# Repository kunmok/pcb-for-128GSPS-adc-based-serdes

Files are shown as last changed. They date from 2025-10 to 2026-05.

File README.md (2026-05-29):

# PCB for ADC-Based 128 GBaud/s SerDes Receiver
This repository contains the PCB design files for the ADC-based 128 Gbaud/s SerDes Rx project.
The project, named "PDMLSE", refers to a DSP-assisted non-linear equalizer implemented in the Intel16 chip (Q4 2024 Shuttle). 

For more details about the designs and layout, please refer to the [TestPlan.pdf](https://github.com/kunmok/pcb-for-128GSPS-adc-based-serdes/blob/main/docs/TestPlan.pdf), [Fabrication Drawing](https://github.com/kunmok/pcb-for-128GSPS-adc-based-serdes/blob/main/docs/fabrication%20drawing%20with%20blindvia.PDF), [pdmlse_pcb.pdf](https://github.com/kunmok/pcb-for-128GSPS-adc-based-serdes/blob/main/docs/pdmlse_pcb.pdf), or contact Kunmo (kunmok@berkeley.edu). 

# 3D View and PCB Configuration 
## PCB Configuration
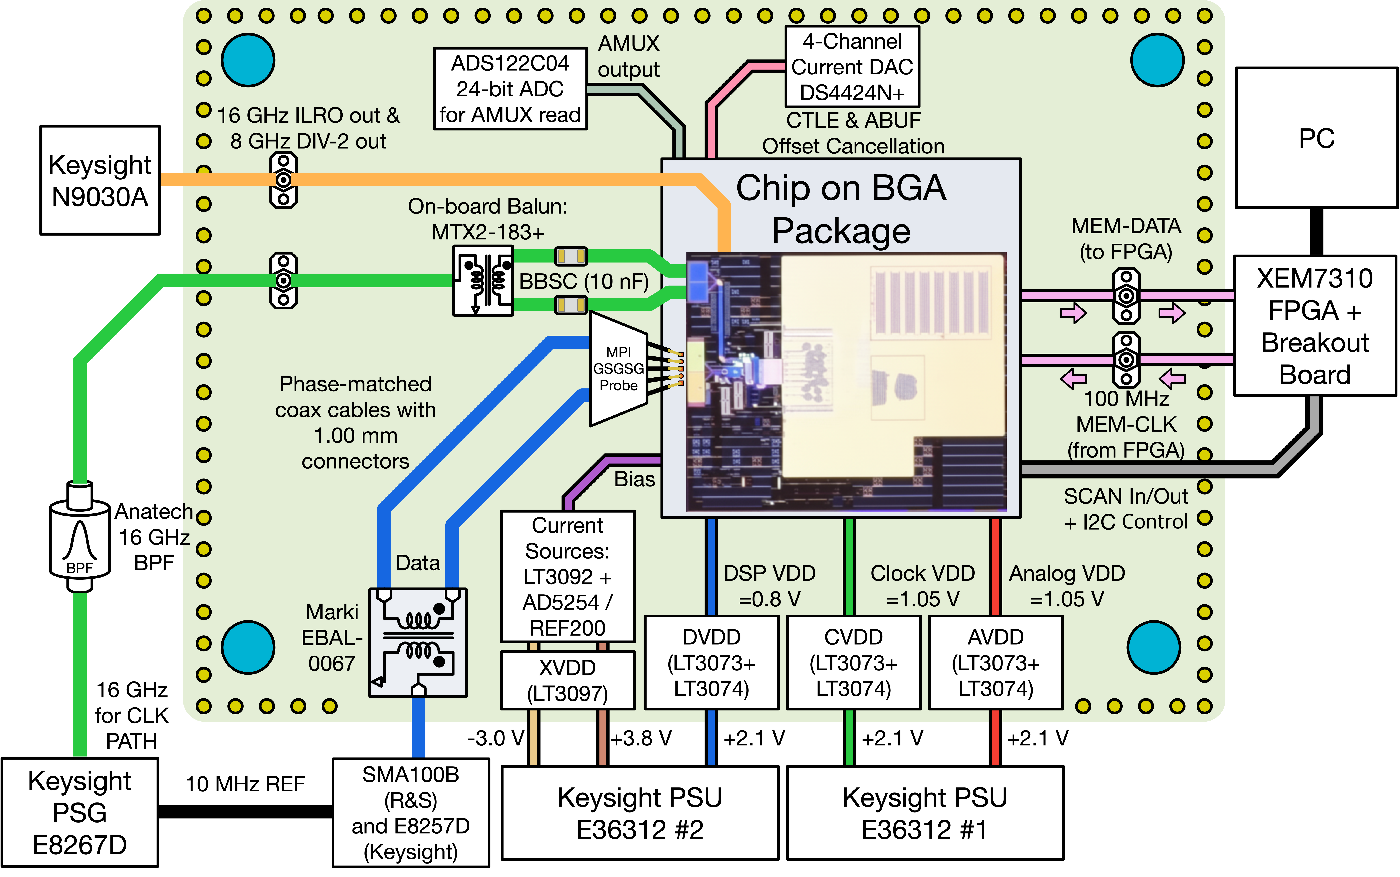
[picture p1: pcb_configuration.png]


### Clock Path (16 GHz) 
- The main 16 GHz clock signal is generated by Keysight’s PSG E8267D and subsequently filtered using an bandpass filter from Anatech (AE16000WB11563), featuring a center frequency of 16 GHz, a bandwidth of +/-50 MHz, and an insertion loss of -4.5 dB. To minimize any frequency offset between the clock and data sources, a 10 MHz reference signal is shared between the signal generators, providing sufficient phase coherence. At a 128 GS/s sampling rate, the 8192-sample (49,152-bit) acquisition window corresponds to only 384 ns, confirming stable synchronization with 10 MHz reference and no need for a 1 GHz reference in/out.

- A stripline configuration is employed for the clock transmission line instead of a grounded coplanar waveguide (GCPW) to further reduce potential coupling between the clock and data paths. The stripline structure also offers greater design flexibility for PCB-to-BGA transitions, enabling a more coaxial-like interface and improved signal integrity.

- For differential signal generation, an on-board balun (MTX2-183+) is used in place of an external balun and additional phase-matched cables. This approach significantly reduces both cost and board area. Although Marki's SMT baluns are viable alternatives, they were out of stock with 3 month of lead-time during the component selection stage. The balanced output of the balun is AC-coupled through Murata BBSC-series DC blockers before being routed to the BGA package.

### Data Path (simulated and measured from 1 GHz to 100 GHz). This path is on the package - not part of the PCB design. 
- Unlike the clock path, the data path is not routed through the PCB. This decision was made because the foundry-provided package has a thickness of 1.2 mm, which introduces significant parasitic inductance through the plated through-holes. This inductance creates a pronounced notch near 60 GHz in the insertion loss profile. The resulting loss could not be adequately compensated by the on-chip CTLE, and therefore, the data signal is directly delivered to the chip using a probe-based approach. The probe landing pads, along with the transmission path between the probe pad, C4 bumps, and on-chip matching network, were modeled and verified using full 3D EM simulations.

- To measure the return loss of the passive front-end matching network, we utilized a Keysight N5290A PNA equipped with an N5293AX03 extension module, alongside an MPI GSGSG probe and calibration substrate. The probe features 1.0mm connectors with a 150 um tip pitch. While a tighter pitch generally yields superior high-frequency performance, the probe landing pad dimensions and pitch were constrained by the package manufacturer's design rules; 150 um was the minimum pitch compliant with DRC requirements.

### Ground Plane and Signal Isolation Strategy
- This PCB uses a single, continuous ground plane shared across seven power domains (AVDD, CVDD, DVDD, XAVDD (±2.5 V), and XDVDD (2.5 V / 3.3 V)). A unified ground provides a more predictable return path, particularly because full-board HFSS simulation is impractical given the board’s size and complexity. To reduce unwanted coupling between domains, the 16-GHz clock routing is confined to the left side of the board, while digital control and interface signals (I²C bus, scan-chain bus, memory read channel, and associated clocks) are routed on the right. The regulated power supplies are crammed in the south side, and analog bias current generation components and routings are placed in the bottom side of the board. The same unified-ground strategy is also used in the IC. On-chip, the analog, clock, and digital supply domains are more tightly partitioned through floorplanning, dedicated decoupling, and guard structures to mitigate coupling.
- During testing, all bench power supplies are operated with their local return (floating with respect to earth), and their earth GND (green port) is not connected to the PCB. This is intentional: the RF return of the 16-GHz clock source (Keysight E8267D PSG) is inherently referenced to earth ground, and the clock source remains continuously connected to the board. As a result, the PCB is earth-referenced through a single point (the RF source connection), effectively implementing a star-ground configuration and avoiding unintended ground loops through multiple instruments. The GSGSG probe is also earth-referenced; however, it primarily provides a return path for the package ground rather than the PCB ground. While the PCB and package ultimately share a common ground, they are separated by finite impedance, so these ground references are not strictly identical at high frequency.

### Power Supply Network
- A cascaded LDO topology—comprising LT3073 followed by LT3074—was implemented to enhance the overall PSRR.
- Murata's NFM-series capacitors are mainly used as decaps. Decaps on L1 (front side) are mainly 10 uF NFM capacitors, and decaps on L6 (back side) are 1 uF NFM capacitors.
- Unlike the common practice of selecting three different capacitor values to cover a broad frequency range, this design uses only two values. The Murata NFM decaps exhibit a very high self-resonant frequency, so their self-resonant behavior does not require careful staggering across multiple values. The smaller 1 uF value on L6 is chosen to account for the via inductance between L1 and L6.
- On the chip side, a substantial amount of MIM decaps plus MOM caps are connected in series with a 0.5 Ω resistance. This intentional ESR overdamps the on-chip PDN, improving resiliency against Ldi/dt noise. This behavior was verified via Spectre simulation.

### Bias Generation
- Backside of the PCB mostly contain bias generation circuit. For bias current generation, a combination of LT3092 and AD5252/AD5254 series digitally programmable resistors was used, enabling flexible bias-level optimization through I2C control.
- REF200s are used for non-programmable bias (cascode bias, CMFB OTA bias, and misc 100 uA). 

### AMUX for Analog Signal Monitoring and CTLE+ABUF Offset Cancellation 
- The chip integrates an on-chip analog multiplexer (AMUX) to monitor various DC bias points, including the CTLE and ABUF bias and output DC voltages as well as local VDD nodes across the die. The AMUX output is routed to an on-board unity-gain buffer, which then drives a 24-bit ADC (ADS122C04) for precision measurement. In addition, a DS4424N+ four-channel current DAC is used for CTLE and ABUF offset cancellation.

## PCB Front-Side: 16 GHz CLK Path, LDOs, ADC, and Connectors
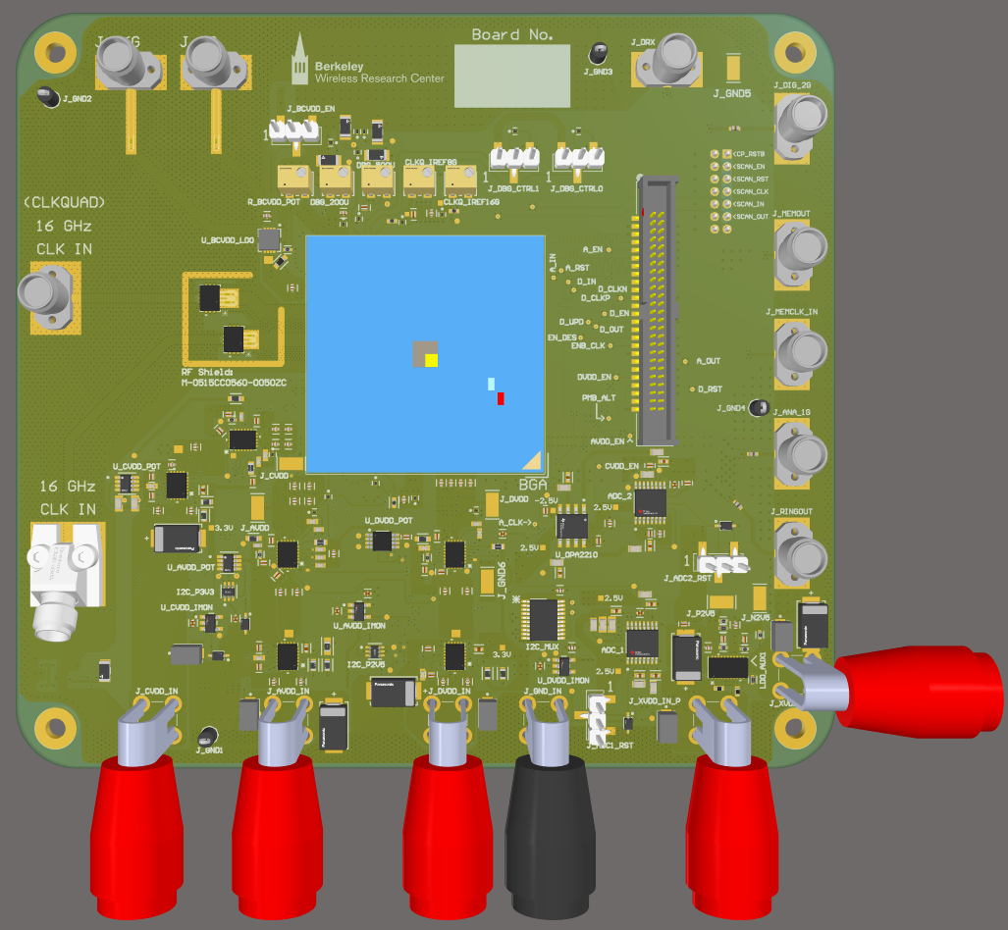
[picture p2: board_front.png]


## PCB Back-Side: Bias Generation (Fixed and Programmable) and Offset Cal IDAC
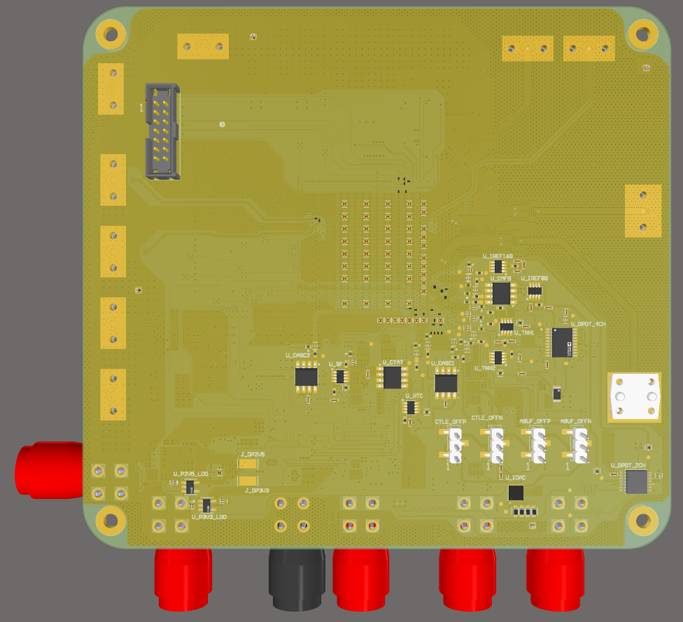
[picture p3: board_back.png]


## Photos 
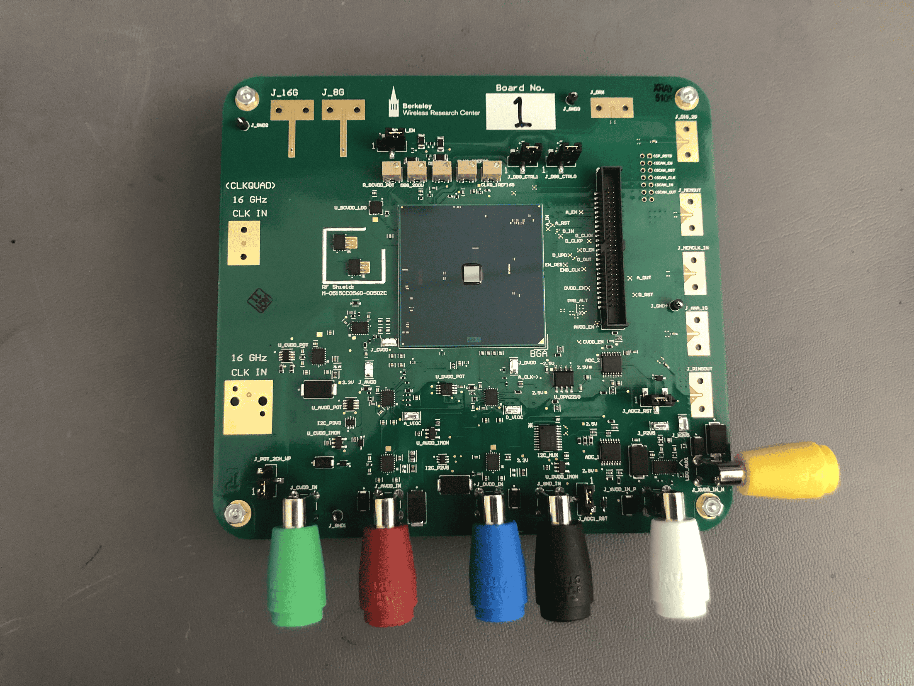
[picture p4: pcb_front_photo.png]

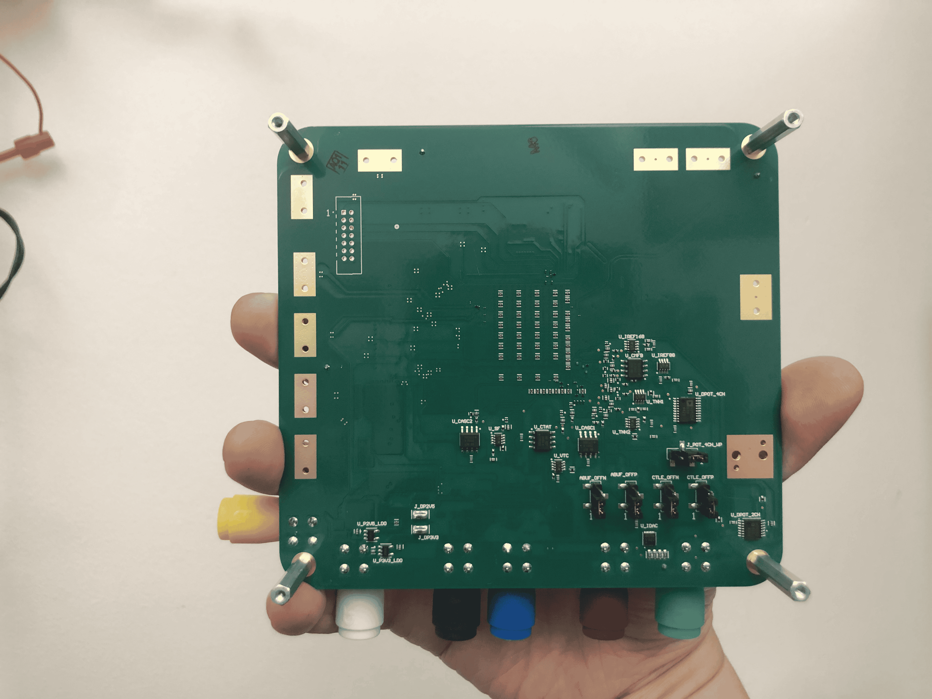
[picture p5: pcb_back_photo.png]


## Author

Designed by **Kunmo Kim** — [kunmo.kim0225@gmail.com](mailto:kunmo.kim0225@gmail.com) ·
[kunmok.github.io](https://kunmok.github.io)

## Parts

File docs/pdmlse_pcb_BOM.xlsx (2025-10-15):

Line # | Name | Description | Designator | Quantity | Alternative Group Name | Manufacturer 1 | Manufacturer Part Number 1 | Supplier 1 | Supplier Part Number 1 | Supplier Unit Price 1 | Supplier Subtotal 1
1 | 878980304 | No Description Available | ABUF_OFFN, ABUF_OFFP, CTLE_OFFN, CTLE_OFFP, J_POT_2CH_WP, J_POT_4CH_WP, J_ADC1_RST, J_ADC2_RST, J_BCVDD_EN, J_DBG_CTRL0, J_DBG_CTRL1 | 11 |  | Molex | 87898-0304 | Digikey | WM20562-ND | 0.7 | 4.2
2 | ADS122C04IPWR | IC ADC 24BIT SIGMA-DELTA 16TSSOP | ADC_1, ADC_2 | 2 |  | Texas Instruments | ADS122C04IPWR | Digikey | 296-50885-6-ND | 8.46 | 16.92
3 | BC04306608DXBAJ | No Description Available | C1_0, C2_0, C5_0 | 3 |  | Vishay | BC04306608DXBAJ | Mouser | 77-BC04306608DXBAJ | 1.45 | 4.35
4 | NFM15PC915D0E3D | CAP FEEDTHRU | C1_1, C1_13, C2_1, C2_2, C3_1, C3_2, C3_11, C4_1, C4_11, C5_1, C5_3, C5_11, C6_1, C6_3, C6_11, C7_1, C7_2, C7_11, C8_2, C8_11, C9_2, C9_11, C10_11, C11_2, C11_11, C12_11, C13_2, C13_11, C14_2, C14_11, C15_2, C15_11, C16_11, C17_11, C18_11, C19_11, C21_2, C23_1, C24_1, C32_1, C33_1, C34_1, C35_1, C36_1, C37_1, C46_1, C47_1, C57_1, C58_1, C59_1, C60_1, C61_1, C62_1, C82_1, C83_1 | 55 |  | Murata | NFM15PC915D0E3D | Digikey | 490-NFM15PC915D0E3DCT-ND | 0.0768 | 4.22
5 | EEF-CX0J101R | CAP ALUM POLY 100UF 20% 6.3V SMD | C1_2, C4_2, C18_1, C43_1, C79_1 | 5 |  | Panasonic | EEF-CX0J101R | Digikey | PCE4278CT-ND | 1.2 | 6
6 | 1u | 0402(1005M) 4V 1.0UF +/- 20% 3 T | C1_3, C12_1, C13_1, C14_1, C15_1, C16_1, C16_2, C17_1, C17_2, C18_2, C19_2, C20_2, C21_1, C22_1, C25_1, C26_1, C28_1, C42_1, C48_1, C49_1, C50_1, C51_1, C52_1, C53_1, C54_1, C56_1, C67_1, C68_1, C69_1, C70_1, C71_1, C72_1, C73_1, C74_1, C75_1, C76_1, C77_1, C78_1, C84_1, C86_1, C87_1, C88_1, C89_1, C90_1, C91_1, C92_1, C93_1, C95_1, C96_1, C97_1, C98_1, C99_1, C100_1, C101_1, C102_1, C103_1, C104_1, C105_1, C106_1 | 59 |  | Murata | NFM15HC105D0G3D | Mouser | 81-NFM15HC105D0G3D | 0.139 | 8.2
7 | LLL1U4R60G435ME22D | Cap Ceramic Monolithic 4.3uF 20% 4V X5R 15% 02404 (0610M) | C1_4, C1_11, C2_3, C2_4, C2_11, C3_3, C3_4, C4_3, C4_4, C5_2, C5_4, C6_2, C6_4, C7_4, C8_4, C9_1, C9_4, C10_1, C10_2, C10_4, C11_1, C11_3, C11_4, C12_3, C12_4, C13_4, C14_4, C15_4, C16_4, C17_4, C18_4, C19_1, C19_4, C20_1, C29_1, C31_1, C39_1, C40_1, C41_1, C44_1, C45_1, C64_1, C65_1, C66_1, C80_1, C81_1, C94_1 | 47 |  | Murata | LLL1U4R60G435ME22D | Digikey | 490-LLL1U4R60G435ME22DCT-ND | 0.073 | 3.43
8 | STMM-107-02-L-D | Connector Header Surface Mount 14 position 0.079 (2.00mm) | P_CLKQUAD | 1 |  | Samtec | STMM-107-02-L-D | Mouser | 200-STMM10702LD | 4.58 | 4.58
9 | 1u | CAP CER 1UF 10V X5R 0402 | C7_3, C8_3, C9_3, C10_3, C27_1, C30_1, C55_1, C85_1 | 8 |  | KEMET | C0402C105K8PACTU | Mouser | 80-C0402C105K8P | 0.058 | 0.58
10 | GRM155R60J475ME47D | Chip Multilayer Ceramic Capacitors for General Purpose, 0402, 4.7uF, X5R, 15%, 20%, 6.3V | C8_1, C38_1, C63_1 | 3 |  | Murata | GRM155R60J475ME47D | Digikey | 490-5915-1-ND | 0.11 | 0.33
11 | PVG5A502C03R00 | PVG5A502C03R00 Resistor Trimmer, Cermet, 5 kOhm, ± 10%, 250 mW, 12 Turn, Multi Turn, Surface Mount | CLKQ_IREF8G, CLKQ_IREF16G, DBG_200U, DBG_500U, R_BCVDD_POT | 5 |  | Bourns | PVG5A502C03R00 | Mouser | 81-PVG5A502C03R00 | 2.44 | 12.2
12 | CSPSBULC1V5AE | No Description Available | CR1_12, CR2_12, CR3_12, CR4_12, CR5_12, CR6_12, CR7_12, CR8_12, CR9_12, CR10_12, CR11_12, CR12_12, CR13_12, CR14_12, CR15_12, CR16_12, CR17_12, CR18_12, CR19_12, CR20_12, CR21_12, CR22_12 | 22 |  | Micro Commercial Components (MCC) | CSPSBULC1V5AE-TP | Mouser | 833-CSPSBULC1V5AE-TP | 0.164 | 3.61
13 | PESD2V0Y1BSFYL | TVS DIODE 2VWM 3VC DSN0603-2 | D1_1, D1_11, D2_11, D3_1, D3_11, D4_3, D4_11, D5_3, D5_11, D6_1, D6_11, D7_11, D8_11, D9_11, D10_11, D11_11, D12_11, D13_11, D14_11, D15_11, D16_11, D17_11, D18_11, D19_11, D15, D16, D17, D18, D19, D20 | 30 |  | Nexperia | PESD2V0Y1BSFYL | Newark | 65AC6223 | 0.072 | 1.8
14 | SMAJ6.0CAHE3/5A | Transient Voltage Suppressor, 6.40 to 231 V, 6 V Stand-off Voltage, Bi-Directional, -55 to 155 degC, 2-pin DO-214AC, Pb-Free, Tape and Reel | D1_2, D2_1, D2_2, D5_1, D7_1 | 5 |  | Vishay Semiconductors | SMAJ6.0CAHE3_A/H | Mouser | 78-SMAJ6.0CAHE3_A/H | 0.61 | 3.05
15 | ESDS311DYFR | ESDS311DYFR One-channel unidirectional device for 3.3V surge protection in SOD-323 package 2-SOT -40 to 125 | D1_3, D2_3, D3_3, D4_1 | 4 |  | Texas Instruments | ESDS311DYFR | Mouser | 595-ESDS311DYFR | 0.59 | 2.36
16 | TCA9544APWR | No Description Available | I2C_MUX | 1 |  | Texas Instruments | TCA9544APWR | Digikey | 296-40576-6-ND | 1.33 | 1.33
17 | LTC4311CSC6#TRPBF | IC POWER MANAGEMENT | I2C_P2V5, I2C_P3V3 | 2 |  | Analog Devices / Linear Technology | LTC4311CSC6#TRPBF | Arrow Electronics | LTC4311CSC6#TRPBF | 3.78 | 7.56
18 | 5019 |  | A_VIOC, D_VIOC, J_AVDD, J_CVDD, J_DP2V5, J_DP3V3, J_DVDD, J_N2V5, J_P2V5 | 9 |  | Keystone Electronics | 5019 | Mouser | 534-5019 | 0.278 | 2.78
19 | ESHF-125-01-L-D-SM | No Description Available | J1_12 | 1 |  | Samtec | ESHF-125-01-L-D-SM | Digikey | SAM15560-ND | 7.15 | 7.15
20 | CON_K_SMT_2d92 | Con RF K | J_8G, J_16G, J_ANA_1G, J_DIG_2G, J_DRX, J_MEMCLK_IN, J_MEMOUT, J_RINGOUT | 8
21 | RT0603BRD0751K1L | RES SMD 51.1K OHM 0.1% 1/10W | R28_4, R29_4, R30_4, R31_4 | 4 |  | Yageo | RT0603BRD0751K1L | Digikey | YAG1681CT-ND | 0.13 | 0.52
22 | RT0603BRE078KL | RT0603BRE078KL SMD Chip Resistor, 8 kOhm, ± 0.1%, 100 mW, 0603 [1608 Metric], Thin Film, High Precision High Stability | R12_1, R23_1, R31_1 | 3 |  | Yageo | RT0603BRE078KL | Mouser | 603-RT0603BRE078KL | 0.1 | 0.3
24 | LT3092ETS8#TRPBF | 200 mA Two-Terminal Programmable Current Source, 0.3 mA Isupply, 8-pin SOT23 (TS8-8), -40 to 125 degC, Pb-Free, Tape and Reel | U_IREF8G, U_IREF16G, U_SF, U_TNH1, U_TNH2, U_VTC | 6 |  | Analog Devices / Linear Technology | LT3092ETS8#TRPBF | Mouser | 584-LT3092ETS8#TRPBF | 5.42 | 32.52
25 | 02K80F-40ML5 | No Description Available | J_MAINQUAD_IN | 1
26 | 5001 | PC TEST POINT MINIATURE BLACK | J_GND1, J_GND2, J_GND3, J_GND4 | 4 |  | Keystone Electronics | 5001 | Newark | 62W5135 | 0.155 | 0.62
27 | LT3097ADJCPBF | No Description Available | LDO_AUX1 | 1 |  | Analog Devices | LT3097ADJC#PBF | Mouser | 584-LT3097ADJC#PBF | 12.52 | 12.52
28 | LT3073AVPBF | No Description Available | LDO_AVDD1, LDO_CVDD1, LDO_DVDD1 | 3 |  | Analog Devices | LT3073AV#PBF | Arrow Electronics | LT3073AV#PBF | 13.18 | 6458.69
29 | LT3074AVPBF | No Description Available | LDO_AVDD2, LDO_CVDD2, LDO_DVDD2 | 3 |  | Analog Devices | LT3074AV#PBF | Mouser | 584-LT3074AV#PBF | 15.24 | 45.72
30 | CRG0603ZR | RES SMD 0 OHM JUMPER 1/10W 0603 | R39_1 | 1 |  | TE Connectivity | CRG0603ZR | Avnet | 75AH8110 | 0.005 | 0.005
31 | CRCW12061K40FKEA | RES Thick Film, 1.4kΩ, 1%, 0.25W, 100ppm/°C, 1206 | R1_0, R2_0, R3_0, R4_0 | 4 |  | Vishay | CRCW12061K40FKEA | Mouser | 71-CRCW1206-1.4K-E3 | 0.11 | 0.44
32 | 1k |  | R1_3, R2_3, R3_3, R4_3, R5_3, R13_1, R16_1, R24_1, R32_1 | 9 |  | Panasonic | ERJ-3EKF1001V | Digikey | P1.00KHCT-ND | 0.1 | 0.9
33 | 50ohm | RT0402BRE0750RL Fixed Resistor, Thin Film, 0.0625W, 50ohm, 50V, 0.1% +/-Tol, 50ppm/Cel, Surface Mount, 0402 | R1_4, R4_4, R5_0, R6_0, R7_4, R12_4, R15_4, R18_4, R19_4, R20_4, R21_4 | 11 |  | Yageo | RT0402BRE0750RL | Digikey | 13-RT0402BRE0750RLCT-ND | 0.133 | 3.06
34 | 2260 |  | R2_1, R3_1, R4_1 | 3 |  | Panasonic | ERJ-2RKF2261X | Mouser | 667-ERJ-2RKF2261X | 0.023 | 0.23
35 | RC0100FR-07100RL | RES SMD 100 OHM 1% 1/32W 01005 | R1_12, R2_12, R3_12 | 3 |  | Yageo | RC0100FR-07100RL | Digikey | 311-100DGCT-ND | 0.1 | 0.3
36 | 51.1k |  | R1_1, R17_1, R25_1 | 3 |  | Panasonic | ERJ-3EKF5112V | Mouser | 667-ERJ-3EKF5112V | 0.1 | 0.3
37 | ERJ-3EKF2001V |  | R10_1, R11_1, R14_1, R15_1 | 4 |  | Panasonic | ERJ-3EKF2001V | Mouser | 667-ERJ-3EKF2001V | 0.034 | 0.34
38 | ERJ-2RKF2003X | Chip Resistor, 200 KOhm, +/- 1%, 100 mW, -55 to 155 degC, 0402 (1005 Metric), RoHS, Tape and Reel | R1_2, R2_2 | 2 |  | Yageo | RC0402FR-07200KL | Newark | 67R9908 | 0.005 | 50
39 | ERJ-2RKF1243X |  | R29_1 | 1 |  | Panasonic | ERJ-2RKF1243X | Newark | 53W4202 | 0.002 | 0.002
40 | ERJ-2RKF2323X |  | R22_1 | 1 |  | Panasonic | ERJ-2RKF2323X | Newark | 53W4280 | 0.004 | 0.004
41 | ERJ-2RKF1003X | RES SMD 100K OHM 1% 1/10W 0402 | R21_1 | 1 |  | Panasonic | ERJ-2RKF1003X | Avnet | 64R5249 | 0.099 | 0.099
42 | ERJ-2RKF8452X |  | R30_1 | 1 |  | Vishay | CRCW040284K5FKED | Newark | 52K7311 | 0.003 | 0.003
43 | ERA-2AEB2492X | RES SMD 24.9K OHM 1% 1/10W 0402 | R3_2, R4_2 | 2 |  | Panasonic | ERJ-2RKF2492X | Digikey | P24.9KDCDKR | 0.0677 | 0.677
44 | ERJ-2RKF2943X |  | R5_1, R18_1 | 2 |  | Panasonic | ERJ-2RKF2943X | Newark | 53W4317 | 0.002 | 0.004
45 | ERJ-2RKF4022X | RES SMD 40.2K OHM 1% 1/10W 0402 | R5_2, R7_2 | 2 |  | Panasonic | ERJ-2RKF4022X | Newark | 73T6521 | 0.004 | 0.008
46 | ERJ-2RKF8060X |  | R6_1, R19_1, R28_1, R9_2 | 3 |  | Panasonic | ERJ-2RKF8060X | Digikey | P806LCT-ND | 0.028 | 0.28
47 | ERA-2AEB103X | RES SMD 10K OHM 0.1% 1/16W 0402 | R6_2, R8_2 | 2 |  | Panasonic | ERA-2AEB103X | Digikey | P10KDCCT-ND | 0.1 | 0.2
48 | ERJ-2RKF1473X |  | R7_1, R20_1, R27_1 | 3 |  | Panasonic | ERJ-2RKF1473X | Mouser | 667-ERJ-2RKF1473X | 0.023 | 0.23
49 | ERJ-2RKF4752X | RES SMD 47.5K OHM 1% 1/10W 0402 | R8_1 | 1 |  | Panasonic | ERJ-2RKF4752X | Newark | 73T6526 | 0.004 | 0.004
50 | ERJ-2RKF2613X |  | R9_1 | 1 |  | Panasonic | ERJ-2RKF2613X | Digikey | P261KLCT-ND | 0.1 | 0.1
52 | ERJ-2RKF1963X |  | R26_1 | 1 |  | Panasonic | ERJ-2RKF1963X | Mouser | 667-ERJ-2RKF1963X | 0.1 | 0.1
53 | CPF0603B1K4E1 | RES SMD 1.4KΩ 0.1% 1/16W 0603 | R34_1, R36_1, R38_1 | 3 |  | TE Connectivity | CPF0603B1K4E1 | Mouser | 279-CPF0603B1K4E1 | 0.26 | 0.78
54 | CH02016-50RGFTA | High precision 50ohm 01005 termination resistor. | R87, R88, R89 | 3 |  | Vishay | CH02016-50RGFTA | Mouser | 71-CH02016-50RGFTA | 7.01 | 21.03
55 | 50ohm_HF | RES SMD 49.9 OHM 1% 1/32W 01005 | R90, R91, R92, R93, R94, R95 | 6 |  | Yageo | RC0100FR-0749R9L | Digikey | YAG6363CT-ND | 0.033 | 0.33
56 | OPA210IDBVR | 3.3-V, LOW-DRIFT, LOW-POWER, SMA | U_AVDD_IMON, U_CVDD_IMON, U_DVDD_IMON | 3 |  | Texas Instruments | OPA210IDBVR | Digikey | 296-OPA210IDBVRCT-ND | 2.99 | 8.97
57 | AD5245BRJZ5-RL7 | IC DGTL POT 5KOHM 256TAP SOT23-8 | U_AVDD_POT, U_CVDD_POT | 2 |  | Analog Devices | AD5245BRJZ5-RL7 | Arrow Electronics | AD5245BRJZ5-RL7 | 1.58 | 3.16
58 | MTX2-183+ | MTX2-183+ | U_BALUN_AA_CLK_16G, U_BALUN_AA_CLKQUAD_16G | 2 |  | Mini-Circuits | MTX2-183+ | Mouser | 139-MTX2-183+ | 9.59 | 19.18
59 | ADP1708ACPZ-R7 | 1 A, Low Dropout, CMOS Linear Regulator, 2.5 to 5.5 V Vin, 0.8 to 5 V Vout, Industrial, 8-pin QFN (CP-8-2), Reel | U_BCVDD_LDO | 1 |  | Analog Devices | ADP1708ACPZ-R7 | Newark | 60AK5387 | 3.45 | 3.45
60 | REF200AU | Dual Current Source / Current Sink, 2.5 to 40 V, 0.1 mA, -25 to 85 degC, 8-pin SOIC (D), Green (RoHS & no Sb/Br) | U_CASC1, U_CASC2, U_CMFB, U_CTAT | 4 |  | Texas Instruments | REF200AU | Digikey | 296-44855-5-ND | 10.25 | 41
61 | AD5252BRUZ10 | IC DGT POT 10KOHM 256TAP 14TSSOP | U_DPOT_2CH | 1 |  | Analog Devices | AD5252BRUZ10-ND | Digikey | AD5252BRUZ10-ND | 7.25 | 7.25
62 | AD5254BRUZ10-ND | IC DGT POT 10KOHM 256TAP 20TSSOP | U_DPOT_4CH | 1 |  | Analog Devices | AD5254BRUZ10-ND | Digikey | AD5254BRUZ10-ND | 10.59 | 10.59
63 | MCP4551T-502E/MS | 8-Bit Single I2C Digital POT with Volatile Memory, 8-pin MSOP, Extended Temperature, Tape and Reel | U_DVDD_POT | 1 |  | Microchip | MCP4551T-502E/MS | Mouser | 579-MCP4551T-502E/MS | 1.2 | 1.2
64 | ds4424n+ | No Description Available | U_IDAC | 1 |  | Analog Devices | DS4424N+ | Mouser | 700-DS4424N | 3.12 | 3.12
65 | OPA2210IDR | IC OP-AMP | U_OPA2210 | 1 |  | Texas Instruments | OPA2210IDR | Digikey | 296-OPA2210IDRCT-ND | 4.25 | 4.25
66 | ADM7160AUJZ-2.5-R2 | IC REG LINEAR 2.5V 200MA TSOT5 | U_P2V5_LDO | 1 |  | Analog Devices | ADM7160AUJZ-2.5-R2 | Mouser | 584-ADM7160AUJZ2.5R2 | 2.21 | 2.21
67 | ADM7160AUJZ-3.3-R7 | IC REG LINEAR 3.3V 200MA TSOT5 | U_P3V3_LDO | 1 |  | Analog Devices | ADM7160AUJZ-3.3-R7 | Arrow Electronics | ADM7160AUJZ-3.3-R7 | 1.27 | 1.27
68 | CT3151-0 | Banana Jack Connector Standard Banana Solder Black | J_GND_IN | 1 |  | Cal Test Electronics | CT3151-0 | DigiKey | BKCT3151-0-ND | 2.55 | 2.55
69 | CT3151-2 | Banana Jack Connector Standard Banana Solder Red | J_AVDD_IN | 1 |  | Cal Test Electronics | CT3151-2 | Digikey | BKCT3151-2-ND | 2.55 | 2.55
70 | CT3151-4 | Banana Jack Connector Standard Banana Solder Yellow | J_XVDD_IN_N | 1 |  | Cal Test Electronics | CT3151-4 | Digikey | BKCT3151-4-ND | 2.55 | 2.55
71 | CT3151-5 | Banana Jack Connector Standard Banana Solder Green | J_CVDD_IN | 1 |  | Cal Test Electronics | CT3151-5 | Digikey | BKCT3151-5-ND | 2.55 | 2.55
72 | CT3151-6 | Banana Jack Connector Standard Banana Solder Blue | J_DVDD_IN | 1 |  | Cal Test Electronics | CT3151-6 | Digikey | BKCT3151-6-ND | 2.55 | 2.55
73 | CT3151-9 | Banana Jack Connector Standard Banana Solder White | J_XVDD_IN_P | 1 |  | Cal Test Electronics | CT3151-9 | Digikey | BKCT3151-9-ND | 2.55 | 2.55
74 | SiliconCap_1 | 939114492510-T3S from Murata | C3_0, C4_0, C_CLKN_AA_CLK_16G, C_CLKN_AA_CLKQUAD_16G, C_CLKP_AA_CLK_16G, C_CLKP_AA_CLKQUAD_16G | 6 |  | Murata | 939114492510-T3S | Digikey | 490-939114492510-T3SCT-ND | 7.03 | 42.18
75 | CON_K_SMT_2d92_alt | Con RF K | J_CLKQUAD_IN | 1
76 | TESTCHIP_UNI3 | UNI2 interposer | U21 | 1
77 | RP73PF1E402RBTD | RES 402 OHM 0.1% 1/10W 0402 | R5_4, R6_4, R10_4, R11_4, R14_4, R17_4 | 6 |  | TE Connectivity Passive Product | RP73PF1E402RBTD | Digikey | A127281DKR-ND - Digi-Reel | 0.17 | 1.02
78 | RP73PF1E18K2BTD | RES 18.2K OHM 0.1% 1/10W 0402 | R22_4, R23_4, R24_4, R27_4, R32_4, R35_4 | 6 |  | TE Connectivity Passive Product | RP73PF1E18K2BTD | Digikey | A127440DKR-ND - Digi-Reel | 0.19 | 1.14
79 | ERA-2AEB101X | RES SMD 100 OHM 0.1% 1/16W 0402 | R2_4, R3_4, R8_4, R9_4, R13_4, R16_4 | 6 |  | Panasonic | ERA-2AEB101X | Digikey | P100DCDKR-ND - Digi-Reel | 0.1 | 0.6
80 | DNP | DO NOT POPULATE | R33_1, R35_1, R37_1, | 3

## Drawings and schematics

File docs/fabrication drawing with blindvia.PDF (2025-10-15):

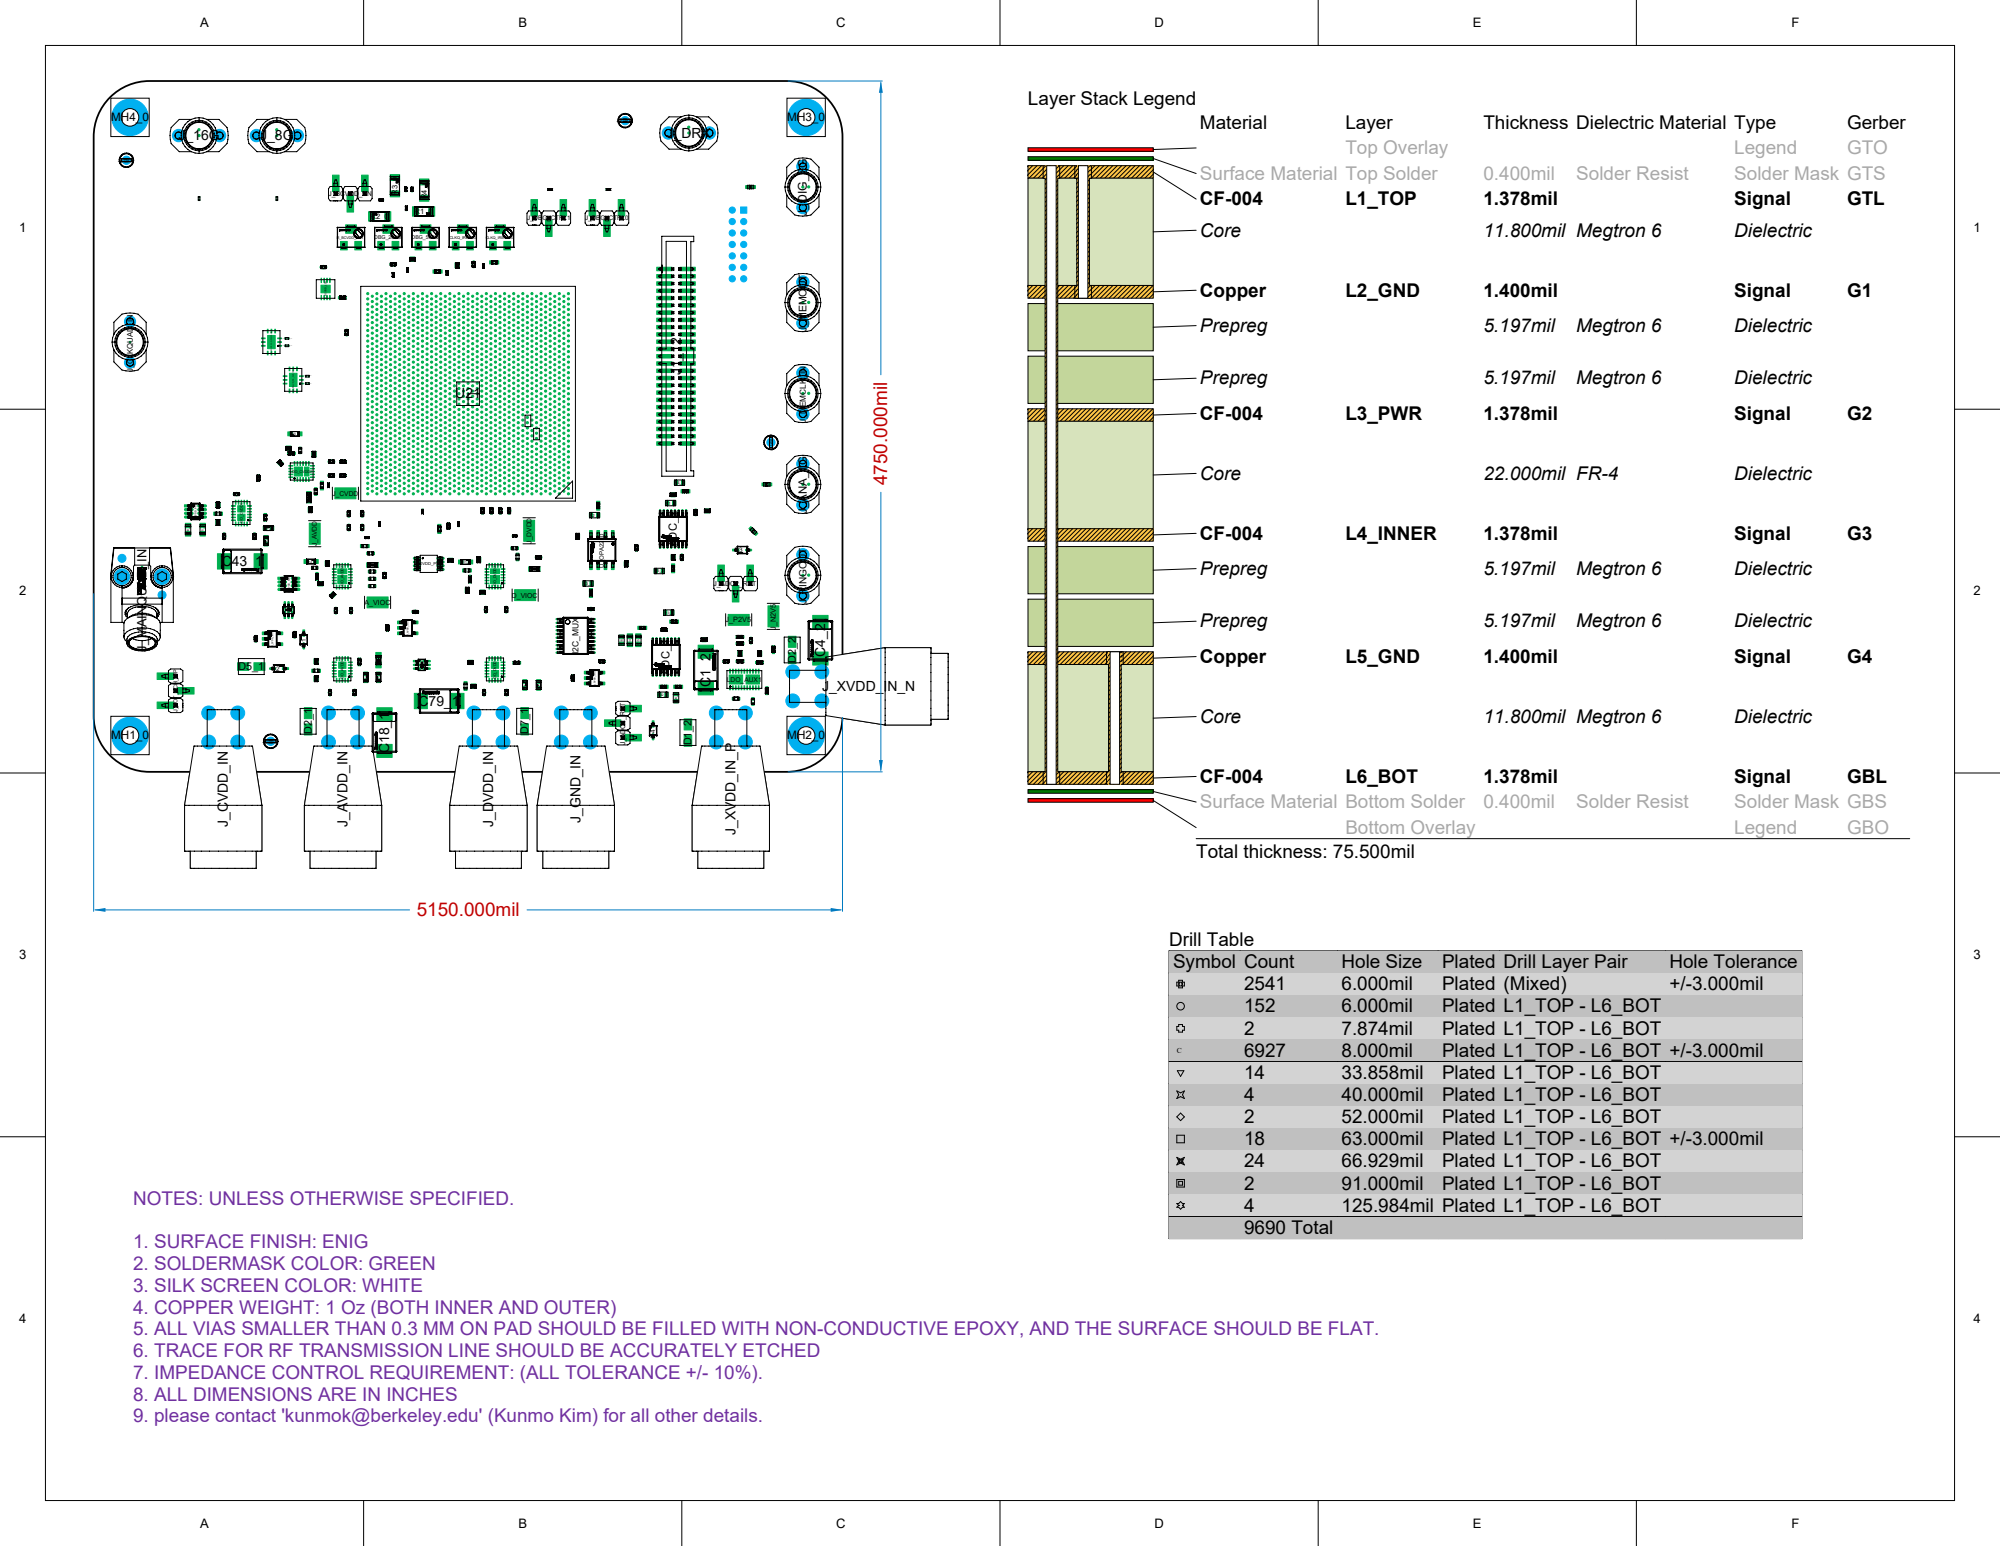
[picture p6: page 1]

NOTES: UNLESS OTHERWISE SPECIFIED.

1. SURFACE FINISH: ENIG
2. SOLDERMASK COLOR: GREEN
3. SILK SCREEN COLOR: WHITE
4. COPPER WEIGHT: 1 Oz (BOTH INNER AND OUTER)
5. ALL VIAS SMALLER THAN 0.3 MM ON PAD SHOULD BE FILLED WITH NON-CONDUCTIVE EPOXY, AND THE SURFACE SHOULD BE FLAT.
6. TRACE FOR RF TRANSMISSION LINE SHOULD BE ACCURATELY ETCHED
7. IMPEDANCE CONTROL REQUIREMENT: (ALL TOLERANCE +/- 10%).
8. ALL DIMENSIONS ARE IN INCHES
9. please contact 'kunmok@berkeley.edu' (Kunmo Kim) for all other details.

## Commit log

2025-11-16 updated pcb_configuration.png
2026-02-23 updated pcb configuration png file
2026-02-23 revised ground strategy
2026-05-27 extra comments on decoupling capacitor selection
